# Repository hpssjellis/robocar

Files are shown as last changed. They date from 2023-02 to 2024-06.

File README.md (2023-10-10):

# robocar
Shredder Robot Toy Car Arduino hacked for machine learning with the PortentaH7 and vision shield

Started Feb 12th, 2023

Edgeimpulse Blog about version 1 here  https://docs.edgeimpulse.com/experts/image-projects/arduino-portenta-h7-self-driving-rc-car

Code should end up here in this folder of my Arduino Library the Portenta Pro Community Solutions.  
If you understand the referencing sytem it is in the "dot55" area.

https://github.com/hpssjellis/portenta-pro-community-solutions/tree/main/examples/dot5-portenta-machine-learning/dot55-robocar

## Main Build steps For Version 1.0.0 at [v1-0-0-robot-car/README.md](v1-0-0-robot-car/README.md)

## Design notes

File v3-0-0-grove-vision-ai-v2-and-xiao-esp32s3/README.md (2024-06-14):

Grove with XIAO-ESP32S3 

Grove can be programmed using the IDF Matter programmer
https://wiki.seeedstudio.com/getting_started_with_matter/

or with AT commands
https://wiki.seeedstudio.com/grove_vision_ai_v2_at/

XIAO ESP32S3 needs this board loaded onto the Arduino IDE. If you have multiple boards put a comma no space between them.

```https://raw.githubusercontent.com/espressif/arduino-esp32/gh-pages/package_esp32_index.json```

Demos for both

https://wiki.seeedstudio.com/grove_vision_ai_v2_demo/

essential reading

https://www.hackster.io/mjrobot/computer-vision-at-the-edge-with-grove-vision-ai-module-v2-0003c7

# good site The main sensecraft site. You don't need to put your address

https://sensecraft.seeed.cc/ai/#/device/local

convert your edgeimpulse int8 quantized model from  .lite   to .tflite   (just change drag and drop onto google colab then change the extension from .loite to .tflite)

```
!pip install ethos-u-vela
!!vela --version
```
Now upload your int8 quat file with new extension .tflite and check that it is there in the main upload area
```
!ls
```
Then run this command, replacing filename with your file name

```
!vela filename.tflite --accelerator-config ethos-u55-64

```

The last command should allow uploading the .tflite labelled file and it downloading the proper .tflite file that sensecraft can then install on your grove vision V2 ai

My Colab is at 

https://colab.research.google.com/drive/1y6_UrLV31ou59T00OmHwqDJIT-tcbCMo?usp=sharing

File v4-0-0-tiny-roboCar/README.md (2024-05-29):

Tiny version of the roboCar made with cardboard and a hot glue gun and cheap parts.

See Brian Plancher Trash Car

https://discuss.tinyml.seas.harvard.edu/t/tinyml-trash-car/1201

And this video

https://youtu.be/gmqgAcnKeFU?si=8e7QMSewyc0nc5lP

## May 2024  update

design: 

cardboard and hot glue
various bread board wires  (22 guage)
1 breadboard
1 Ni-MH 6V battery
2 geared motors individually controlled
1 dual motor driver
1 XIAO  basic control testing
or
1 XIAO-esp32s3 with camera for basic machine learing
or
Xiao-esp32   S3 or C6 with Grove Vision AI V2 and RPI camera  for advanced machine learning

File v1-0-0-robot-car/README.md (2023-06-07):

BLOG POST

# Shredder RoboCar with the Arduino PortentaH7 and Vision Shield.

## TINYML, MACHINE LEARNING, EMBEDDED DEVICES, ARDUINO PORTENTA-H7

Jeremy Ellis

May 30, 2023

I wanted a long-term project for students willing to do extra work and interested in both Arduino microcontrollers and Vision Machine Learning. We took an RC car and converted it to be controlled by the Arduino PortentaH7 and then trained a FOMO Vision [EdgeImpulse.com](https://www.edgeimpulse.com/) model to create a self-driving RoboCar. This high-level, long-term project is great for students who want a harder-than-normal challenge.

We picked a certain RC car "[RC Pro Shredder](https://bchobbies.com/products/shredder112scale4wdbrushedmonstertruck)" that did not use a brushless motor as the programming of brushless motors has extra complexity. We also needed a big motor driver, a servo motor (The Shredder steering motor is a DC motor with a potentiometer), connectors, USB cable and USB battery pack, as well as the ability to 3D Print large objects. See [price-list.md](price-list.md)

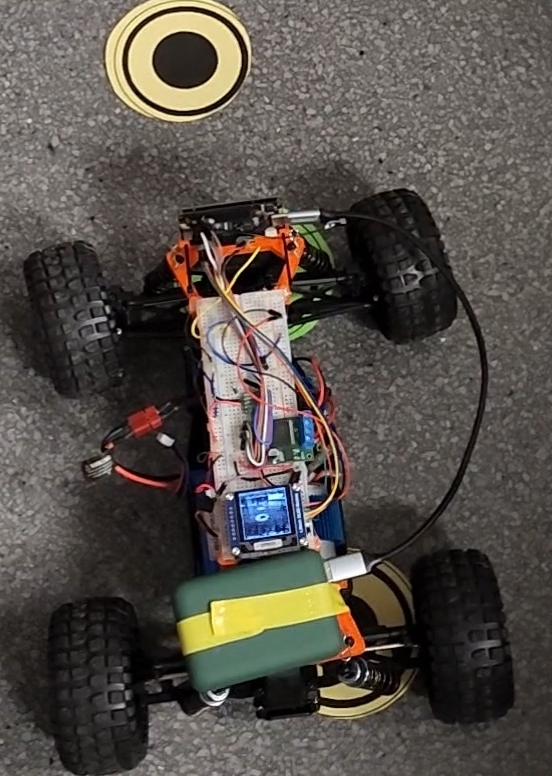
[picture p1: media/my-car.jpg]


## This is a difficult build and may need some adaptations for your project: For example, we used a large print-bed 3D printer to make the 10.5 inch long frame (26.7 cm). You may choose to split that frame up or put the hardware somewhere else on the car.

The software to use is online as part of my Arduino IDE ready library the "[Portenta Pro Community Solutions](https://github.com/hpssjellis/portenta-pro-community-solutions)" in the [dot55 area](https://github.com/hpssjellis/portenta-pro-community-solutions/tree/main/examples/dot5-portenta-machine-learning/dot55-robocar/dot551-robocar-v1). A huge library of ready-made examples to use with the Arduino PortentaH7 and other Arduino MBED boards.

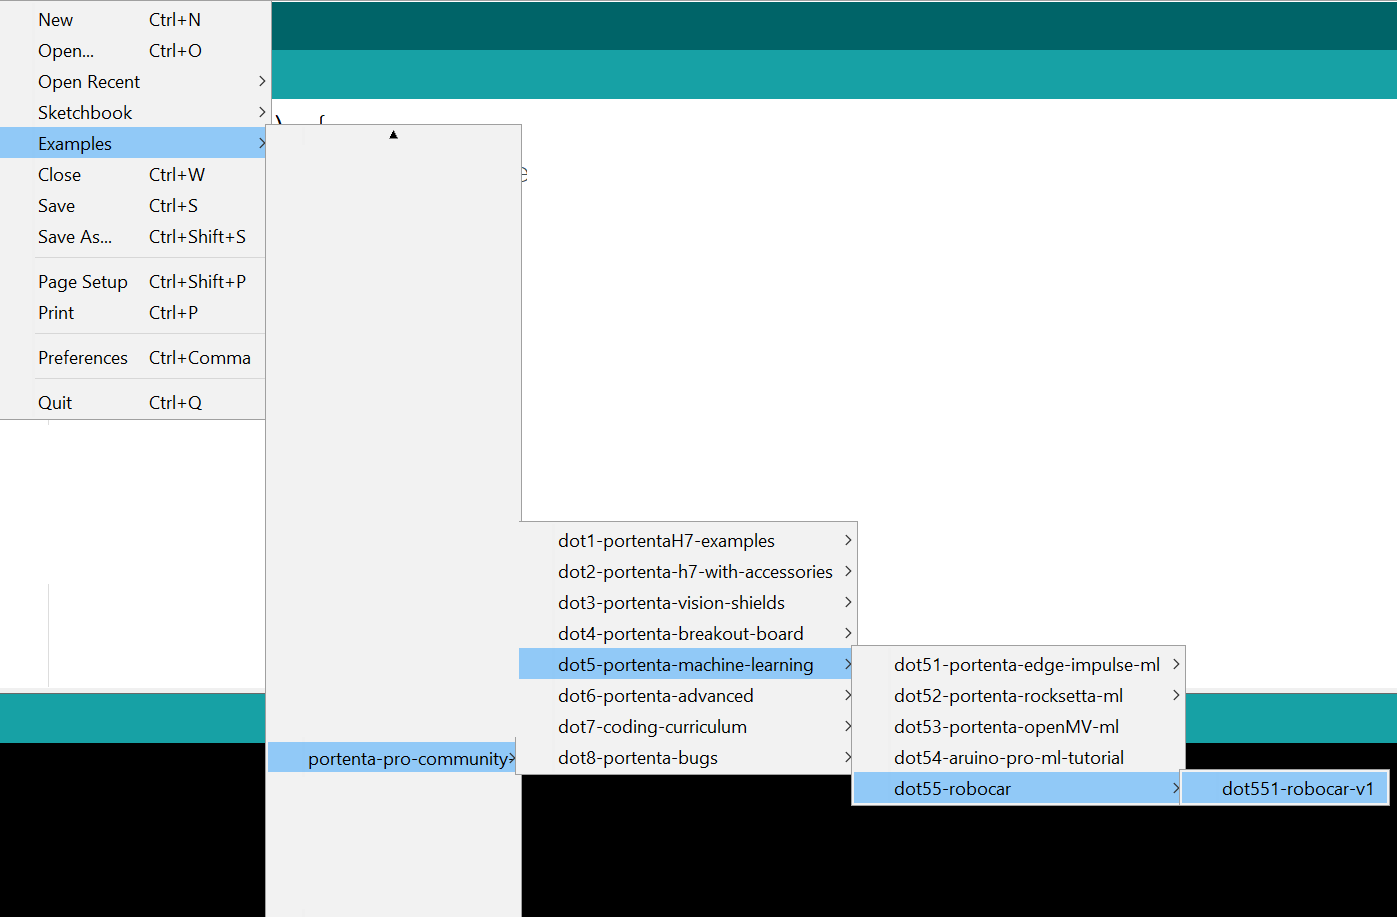
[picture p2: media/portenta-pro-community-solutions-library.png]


## Main Build steps

1. Purchase parts: First, you need to purchase the parts required to build the car. Check out the price list provided and make sure to purchase all the required parts without exceeding your budget. Checkout the price list at [price-list.md](price-list.md)
     ## List of suggested first-time purchases:

      1. [RC-Pro SHREDDER](https://www.rcpro.ca/collections/shredder/products/shredder) $189.99 CDN  
      2. [WSD1302 plug set](https://www.rcsuperstore.com/ws-deans-2-pin-ultra-plug-set-one-male-one-female-included/) 2 sets  $2.99 USD
      2. [Bullet Connectors](https://www.amazon.com/AIRIC-Bullet-Connectors-Insulated-Terminals/dp/B08ZSQZCCR?th=1) only need 2 female bullet connectors this is a set of 50 for  $11.99 USD
      4. [Big VNH5019 Motor Driver Carrier](https://www.pololu.com/product/1451) $44.95 USD 
      5. [3 wire Servo ](https://www.rcpro.ca/collections/shredder/products/shredder-3-wires-19gram-metal-gear-servo)  $24.99 CDN
      6. [Arduino PortentaH7](https://store-usa.arduino.cc/products/portenta-h7)  $103.40 USD 
      7. [Arduino LoRa Vision Shield](https://store-usa.arduino.cc/products/arduino-portenta-vision-shield-lora%C2%AE) $63.25 USD
      8. [https://www.waveshare.com/1.5inch-oled-module.htm](https://www.waveshare.com/1.5inch-oled-module.htm) $12.99 USD
      9. Will also need a USB-C cable, USB battery pack,  micro-sd card and polarized sunglasses. A 3D printer would be useful.

3. Have fun with the RC car: Without breaking it, charge the battery and drive it around to test the tight turning circle diameter and slowest speeds that it still moves.
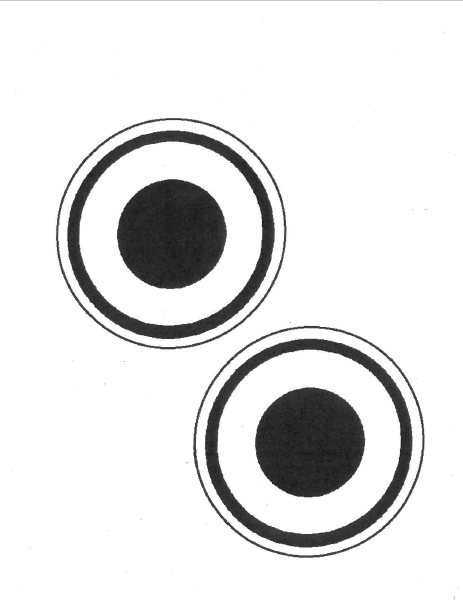
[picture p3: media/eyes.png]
4. Find objects to track: To train your model, you need to find objects to track. You can use double-sided black circles on photocopy paper and cut them out. [../media/eyes-pdf.pdf](../media/eyes-pdf.pdf)   
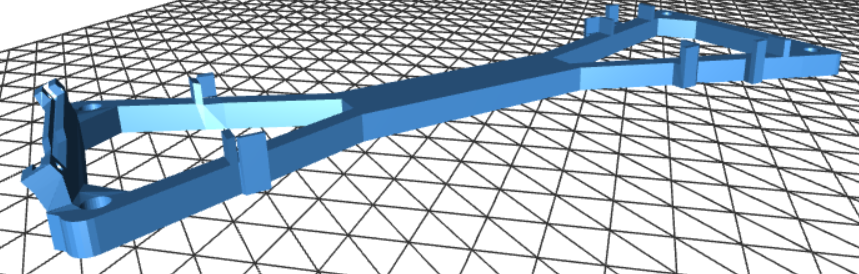
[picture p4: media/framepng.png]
5. Build the car frame:     3D print the car frame using the provided STL files [../media/rc-Car-frame28-22degrees-V28-22-degrees.stl](../media/rc-Car-frame28-22degrees-V28-22-degrees.stl) or these smaller prints [../media/rc-Car-frame27-bread-front.stl](../media/rc-Car-frame27-bread-front.stl)   and [../media/rc-Car-frame27-bread-back.stl](../media/rc-Car-frame27-bread-back.stl) or make one with wood or cardboard. Make sure to attach the PortentaH7 with LoRa vision shield on the car (check the image to see which way the portenta is oriented with the USB cable. The USB cable should protude to the right of the car.) along with a USB-C cable with a battery pack, and attach it to the car while it still has the RC components working. This allows you to drive the car while taking lots of images on the SD card. You will need this program [dot362-png-to-sd-card.ino](https://github.com/hpssjellis/portenta-pro-community-solutions/blob/main/examples/dot3-portenta-vision-shields/dot36-camera-png-to-web/dot362-png-to-sd-card/dot362-p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). Note line 75 ```int myDelay = 10000;``` sets a variable to take an image every 10 seconds. Change that number to about 500 to take lots of .PNG pictures. Depending on how well the Portenta SD Card fits you might get several bad photos. An easy soultion is to just take many more photos. You might want to attach sunglasses to the model if reflections are a problem when using the car inside.

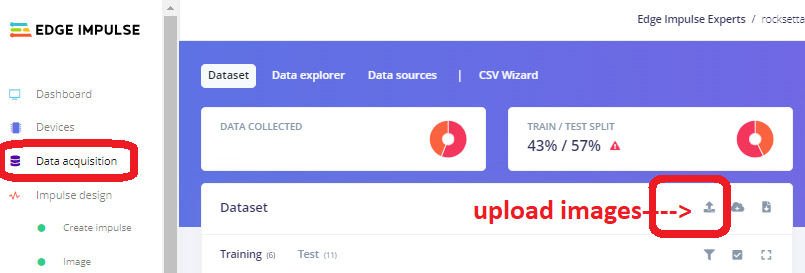
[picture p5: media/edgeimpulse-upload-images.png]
5. Train the model: Upload the images to Edgeimpulse.com  and train a FOMO model on EdgeImpulse.com, or grab the main one I use: [here ei-ei-v25-fomo-eyes-shades-arduino-1.0.2.zip](https://github.com/hpssjellis/portenta-pro-community-solutions/blob/main/zipped-libraries/edge-Impulse/arduino-exported/Portenta-Camera/ei-ei-v25-fomo-eyes-shades-ar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). The following steps to train the machine learning model are mirrored on this site with images at [https://hpssjellis.github.io/multi-language-edgeimpulse-tutorial-vision-cell-phone/](https://hpssjellis.github.io/multi-language-edgeimpulse-tutorial-vision-cell-phone/)
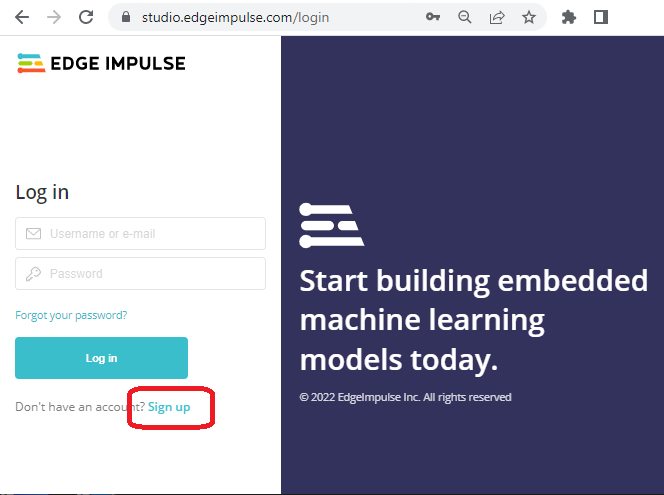
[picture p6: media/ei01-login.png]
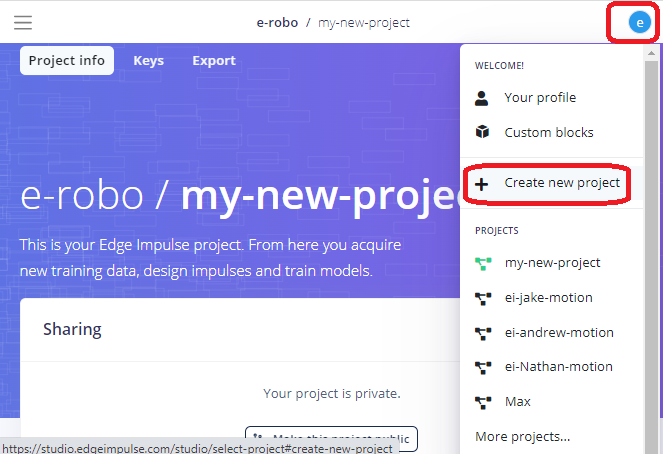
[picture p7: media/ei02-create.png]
      1. login or register for [Edgeimpulse.com](Edgeimpulse.com) <br>  <br> 
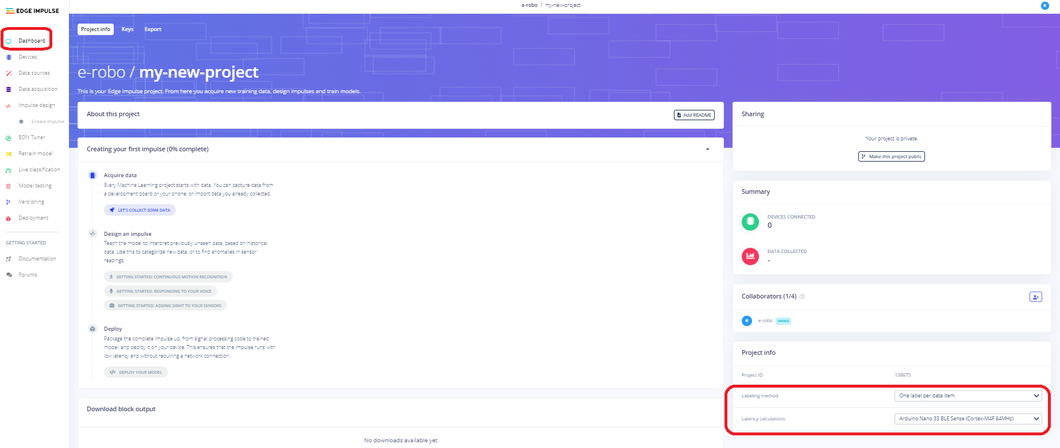
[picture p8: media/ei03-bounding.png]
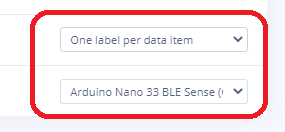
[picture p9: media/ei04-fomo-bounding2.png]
      2. On the dashboard, go to the far right and change the label type from "one label" to "bounding boxes." This sets up the model for FOMO (faster objects, more objects) vision. Also, set Target Device to "Arduino PortentaH7 (Cortex M7 480 MHz)" <br> <br><br>
      3. Use the menu connect devices and go to uploader and upload your images that you took of the car driving around your object to detect
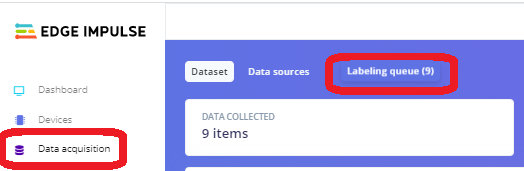
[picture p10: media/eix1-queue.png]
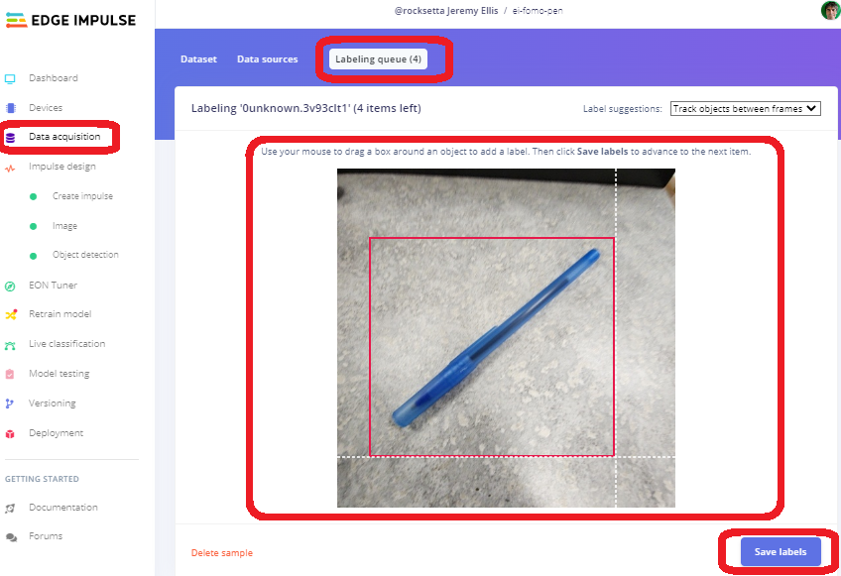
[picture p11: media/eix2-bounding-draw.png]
      4. Go to the menu item Data Acquisition and click on the "Queue" and start drawing bounding boxes around your objects. <br><br> "Make sure the label is the same for all of them I use "1eye". The number in front of your label is very important for an easy way to determine which label you are analyzing . <br>
      5. Once all images are labelled, create your standard FOMO model by clicking "create impulse" and choose the standard Edge Impulse image and object detection blocks. Check before saving the impulse that it has only one object.
      6. For the menu item "image" make sure you are saving Grayscale not RGB and save it. 
      6. In the "Image" menu item, click on "Generate Features" wait a few minutes to see the "Feature explorer". Check for weird images and delete or change them as needed.
      7. In the menu item "Object Detection" set number of training cycles to about 220 (or whatever works for your project). Add "Data Augmentation" and "start Training" takes about 8 minutes.  
      8. Check your F1 score and confusion matrix, which should be reasonably good hopefully above 80% for the background and the 1eye labelled object
      9. Test the model on your phone or download it to the Arduino. A reminder this is an Arduino library so you will need to  upload it into the Arduino IDE as a zipped library.
      10. Check the library file name so you can change the library that is in the default program to the new name.
      11. Always place the car on a small box when testing it as it could jump off the table and break.
      12. Flash the code to the Portenta connected to your car. Make sure both batteries are charged. 
      13. Always unplug both batteries when you have finished testing the car.
      14. Return to Edgeimpulse and try to improve your model.
6. Download the exported Edgeimpulse arduino library and install the .zip file into the Arduino IDE (Sketch--> Include Library --> Add .ZIP Library). This is a long compile depending on your computer speed. Expect about 20 min for this to complete the first time, about 3 min each time after that. Just testing that this code compiles and can load onto the Portenta with vision shield and a serial monitor output shows that it is working is a huge step. Well done if it works.
7. Load the Arduino sketch [dot551-robocar-v1.ino](https://github.com/hpssjellis/portenta-pro-community-solutions/blob/main/examples/dot5-portenta-machine-learning/dot55-robocar/dot551-robocar-v1/dot551-robocar-v1.in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) but loading it is easy from the Arduino IDE installed "Portenta Pro Community Solutions" library sketch dot551 (check for newer versions) as it will also load the included file ```#include "edge-impulse-advanced-v2.h"```. If you want you can manually load that included file from: [edge-impulse-advanced-v2.h](https://github.com/hpssjellis/portenta-pro-community-solutions/blob/main/examples/dot5-portenta-machine-learning/dot55-robocar/dot551-robocar-v1/edge-impulse-advance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). It is just a way to get rid of the complex coding, so your main file only has the necessary code that you might want to change.
8. If you have the (Optional but very useful for debugging) WaveShare grayscale 128 x 128 OLED then attach the correct pins to the Portenta: 
  * black to GND, 
  * red to 3v3, 
  * blue DIN (mosi) to D8, 
  * yellow (sck) to D9, 
  * orange (cs) to D7, 
  * green (dc) to D6, 
  * white (reset) not needed  
<br>and run the code and observe your model if it works. This code [dot229-128x128-gray-oled.ino](https://github.com/hpssjellis/portenta-pro-community-solutions/blob/main/examples/dot2-portenta-h7-with-accessories/dot22-actuators/dot229-128x128-gray-oled/dot229-1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) can be used just to test the WaveShare OLED with the Portenta
9. Remove the 5 wire servo that comes with the shredder car and attach the 3 wire servo. The ball joints are a bit difficult to replace. Test the servo Portenta connection with this code [dot221-servo.ino](https://github.com/hpssjellis/portenta-pro-community-solutions/blob/main/examples/dot2-portenta-h7-with-accessories/dot22-actuators/dot221-servo/dot221-servo.ino)   The connections are:    
   * servo red to 6V battery positive
   * servo ground (brown or black) to 6V battery negative
   * servo ground (brown or black) to board GND
   * servo controller (orange or the other color) to board PWM pin D2   
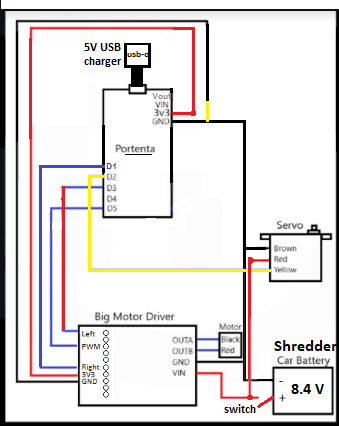
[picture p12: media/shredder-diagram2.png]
Here is an image of the entire wiring diagram  <br>
10. Using a long breadboard attached to the car, connect the Big Motor Drive (Motor Driver test code [dot227-big-dc-motor-driver.ino](https://github.com/hpssjellis/portenta-pro-community-solutions/blob/main/examples/dot2-portenta-h7-with-accessories/dot22-actuators/dot227-big-dc-motor-driver/dot227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) ) See image for pin connections:
  *  Left side of Big Motor Driver board in order from the top (see diagram): D3 - D4 - - D5  3V3  GND - - 
  *  Right side: OutA, OutB to the motor on the Shredder using the [Bullet-Connectors](https://www.amazon.com/AIRIC-Bullet-Connectors-Insulated-Terminals/dp/B08ZSQZCCR?th=1)
  *  Right side continued: GND, VIN to the 7.4 V Li-ion battery on the Shredder using the [ws-deans-2-pin-ultra-plug](https://www.rcsuperstore.com/ws-deans-2-pin-ultra-plug-set-one-male-one-female-included/)  
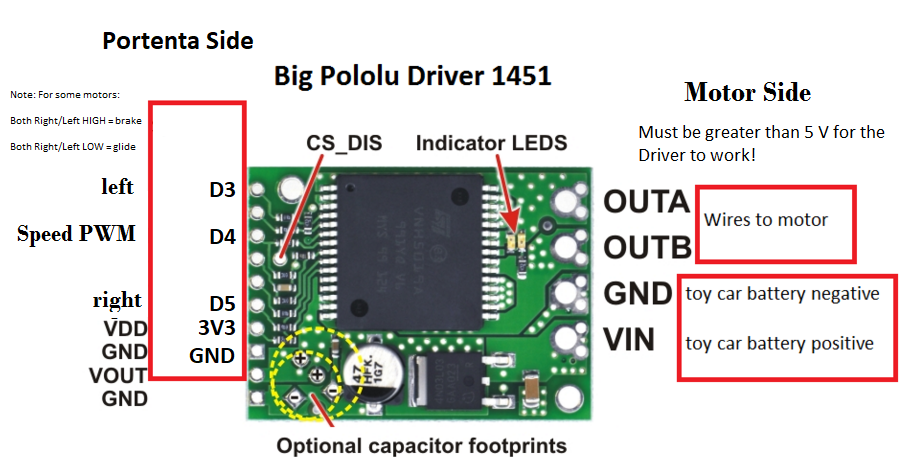
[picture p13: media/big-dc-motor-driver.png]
<br><br> Make sure the high car voltage is kept away from the 5 volt USB input for the Portenta.
11. A tricky part of the car build is getting the main battery power to the big motor driver and deciding on if the main battery is going to power the portenta. We tried step-down 5V regulators etc, but the Portenta seemed very sensitive to power fluctuations when the car was running so I just powered the Portenta with a 5V USB battery pack attached to the top of the breadboard. Your big motor driver will need connectors for both the main battery and the motor. See price list [price-list.md](price-list.md)
12. Test that the mechanical parts of the car are working by running this test code which puts together both the servo and big motor driver: [here ../media/a01-motor-testing.ino](../media/a01-motor-testing.ino). This allows you to check the motor slowest speed and best full turning angle. (Don't push the angles too far as the servo motor complains)
13. Once everything is proven to work, upload the main code again from [here dot551-robocar-v1](https://github.com/hpssjellis/portenta-pro-community-solutions/blob/main/examples/dot5-portenta-machine-learning/dot55-robocar/dot551-robocar-v1/dot551-robocar-v1.in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), (best to load it from hte Portenta Pro Community Solutions library as the included ```edge-impulse-advanced-v2.h``` will be automatically loaded) change a few of the variables such as PWM_MIN and maximum turning angles, and try-out your car.
14. Start editing the code to make it work better.
15. Also edit the 3D Printing to add lights, etc.
16. Share your code on social media and link to twitter @rocksetta 

My student's cars:



# Conclusion

I hope you enjoyed this difficult project, it involved Arduino maker connections to a DC motor and Servo motor with Machine Learning using edgeimpulse.com and problem-solving to improve the Vision FOMO model. When you have the roboCar working, students can start making extensions, such as lighting and battery monitoring, including adaptions for if the car loses the trail. Good luck and I hope you had fun.
<br>

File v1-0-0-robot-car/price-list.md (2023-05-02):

## RoboCar pricelist V1

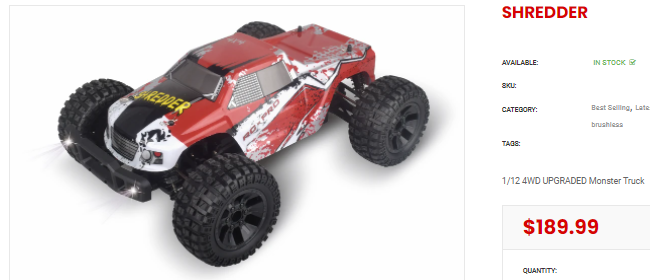
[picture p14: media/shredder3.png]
 [RC-Pro SHREDDER](https://www.rcpro.ca/collections/shredder/products/shredder)   
$189.99 CDN   

(Do not get the more expensive brushless version of the Shredder car as the coding is much more difficult)

# Must also have

 Everyone needs the Big Motor Driver <br>
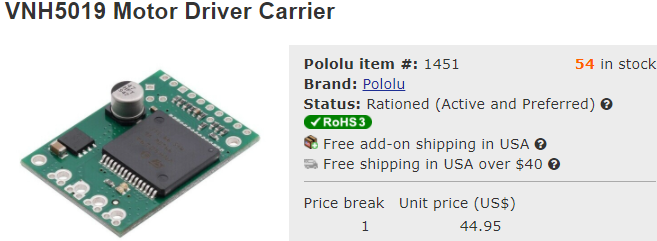
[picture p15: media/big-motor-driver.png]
  [Big VNH5019 Motor Driver Carrier](https://www.pololu.com/product/1451)   
 $44.95 USD

.

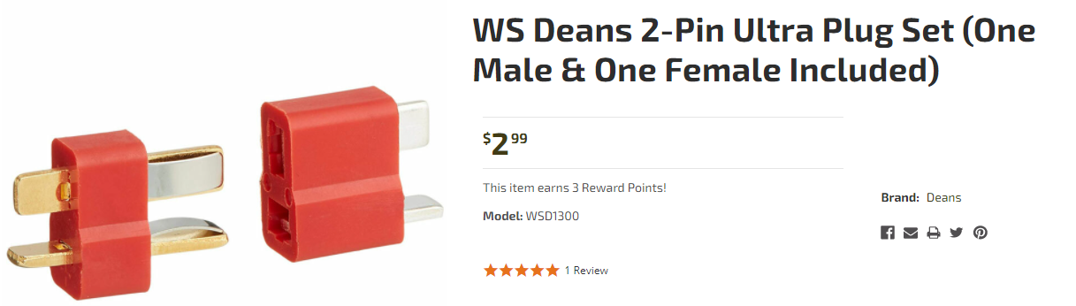
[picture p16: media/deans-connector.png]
 And these plugs you need 2 of the female connector so get 2 sets. https://www.rcsuperstore.com/ws-deans-2-pin-ultra-plug-set-one-male-one-female-included/   

$2.99 USD 

.

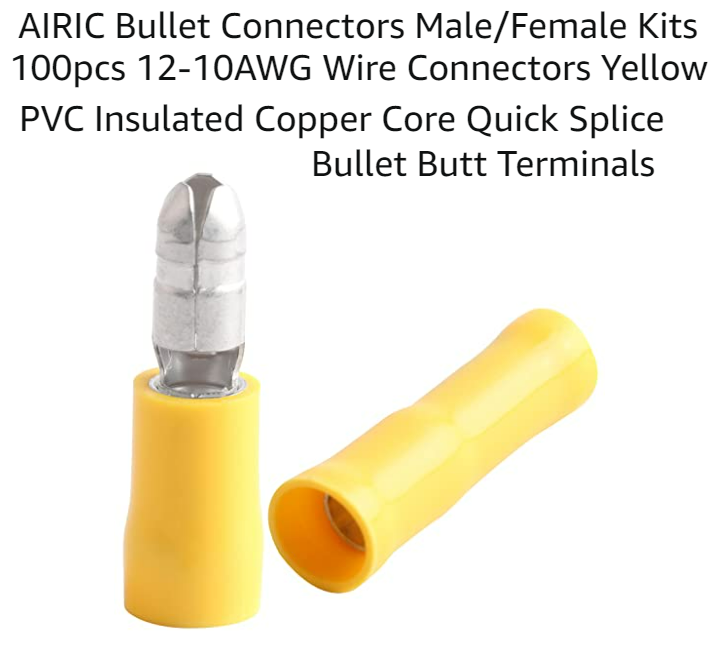
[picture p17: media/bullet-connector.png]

You only need 2 female bullet connectors  https://www.amazon.com/AIRIC-Bullet-Connectors-Insulated-Terminals/dp/B08ZSQZCCR?th=1

this is a set of 50 for  $11.99 USD. 

# Note: 

You can get an extra servo motor as this makes coding much easier than the orginal car above, which uses a DC motor for turning and a potentiometer to determine what angle the motor is at. 
 
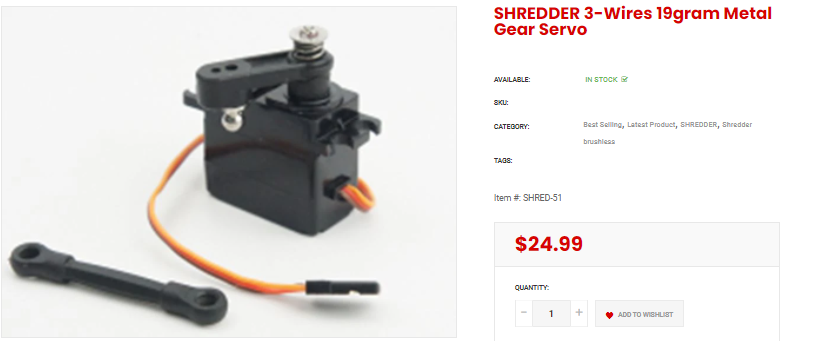
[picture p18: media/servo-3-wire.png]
  Extra [3 wire Servo ](https://www.rcpro.ca/collections/shredder/products/shredder-3-wires-19gram-metal-gear-servo)  

$24.99 CDN

-----

## Note that Microcontrollers improve rapidly. 

Here is the changing list. The 2021 Portenta should last us a few years.   
(Any of the below materials would work fine, just we will be able to do much more with the latest equipment the Portenta and Vision Shield)

## 2021 Microcontroller Price List   
When we combine the PortentaH7 with the LoRa vision shield we have a great Machine Learning duo. But it is expensive.  

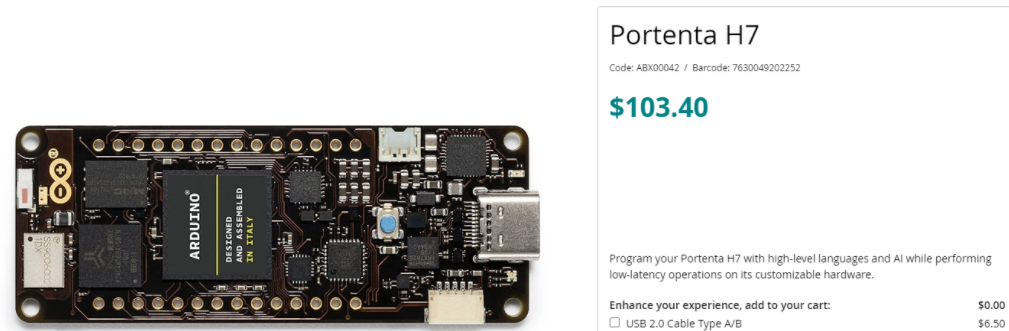
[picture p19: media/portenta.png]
 [Arduino PortentaH7](https://store-usa.arduino.cc/products/portenta-h7)    
$103.40 USD  The base best Arduino

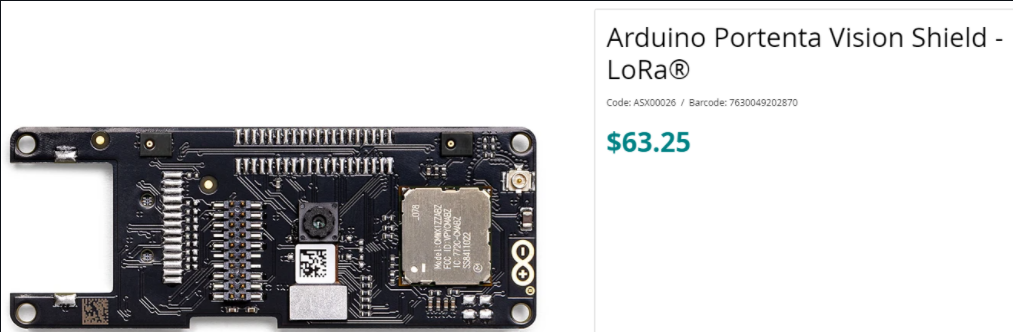
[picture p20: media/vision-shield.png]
 [Arduino LoRa Vision Shield](https://store-usa.arduino.cc/products/arduino-portenta-vision-shield-lora%C2%AE)    
$63.25 USD  allows the Portenta to See and hear and use the LoRaWan networks

The Portenta might need female headers if you don't want to solder wires directly onto it.  Here is a link if you want them. 
The male headers are good to attach the Portenta to a breadboard. Note: The female headers are attached to come up out of the board allowing the HD connectors below the board to connect the Vision shield to.

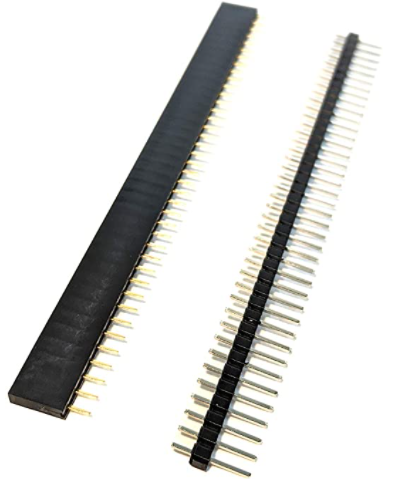
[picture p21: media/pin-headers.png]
 

[10 pack of 40 pin male female headers](https://www.amazon.ca/Pieces-2-54mm-Single-Female-Header/dp/B08CMNRXJ1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)

.

.

## Also to view what you are working on a screen is a good idea

Get the 16 levels of Grayscale Waveshare OLED<br>

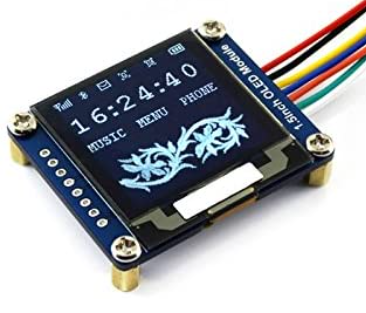
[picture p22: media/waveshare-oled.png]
  [1.5inch OLED Display Module 128x128 16 Gray Scale SPI/I2C Interface SSD1327 Driver Raspberry Pi/Arduino/STM32](https://www.amazon.ca/dp/B079KRC9X3?psc=1&smid=AIVH4OZ6D0Y4K&ref_=chk_typ_imgToDp) $23 CDN 

OR purchase it at [https://www.waveshare.com/1.5inch-oled-module.htm](https://www.waveshare.com/1.5inch-oled-module.htm) 

for $12.99 USD

.

.

...

## List of suggested first time purchase:

1. [RC-Pro SHREDDER](https://www.rcpro.ca/collections/shredder/products/shredder) $189.99 CDN  
2. [WSD1302 plug set](https://www.rcsuperstore.com/ws-deans-2-pin-ultra-plug-set-one-male-one-female-included/) 2 sets  $2.99 USD
2. [Bullet Connectors](https://www.amazon.com/AIRIC-Bullet-Connectors-Insulated-Terminals/dp/B08ZSQZCCR?th=1) only need 2 female bullet connectors this is a set of 50 for  $11.99 USD
4. [Big VNH5019 Motor Driver Carrier](https://www.pololu.com/product/1451) $44.95 USD 
5. [3 wire Servo ](https://www.rcpro.ca/collections/shredder/products/shredder-3-wires-19gram-metal-gear-servo)  $24.99 CDN
6. [Arduino PortentaH7](https://store-usa.arduino.cc/products/portenta-h7)  $103.40 USD 
7. [Arduino LoRa Vision Shield](https://store-usa.arduino.cc/products/arduino-portenta-vision-shield-lora%C2%AE) $63.25 USD
8. [https://www.waveshare.com/1.5inch-oled-module.htm](https://www.waveshare.com/1.5inch-oled-module.htm) $12.99 USD
9. Will also need a usb-C cable, usb battery pack and a micro-sd card polarized sunglasses. A 3D printer might be useful
<br>

Other costs are:  usb-C cable, USB battery pack, 3D Printing ability, general wires and soldering equipment.

## Note: Version 2 is being worked on and will have a slightly different set of hardware

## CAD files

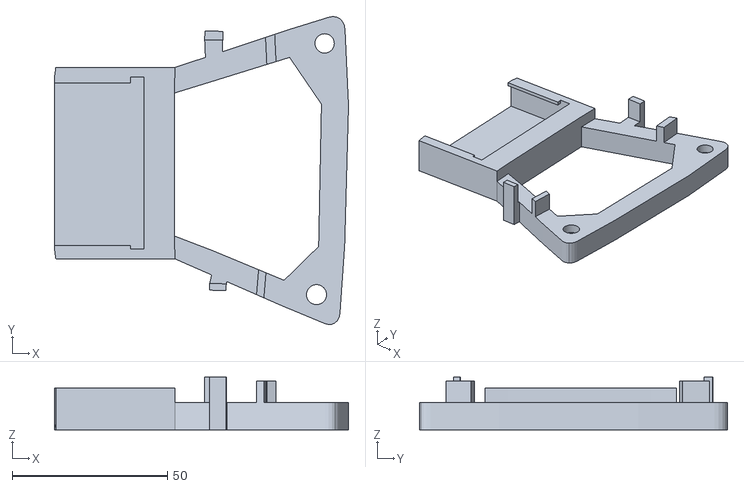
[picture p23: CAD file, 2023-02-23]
media/rc-Car-frame27-bread-back.stl
94.7 x 99.1 x 17.0

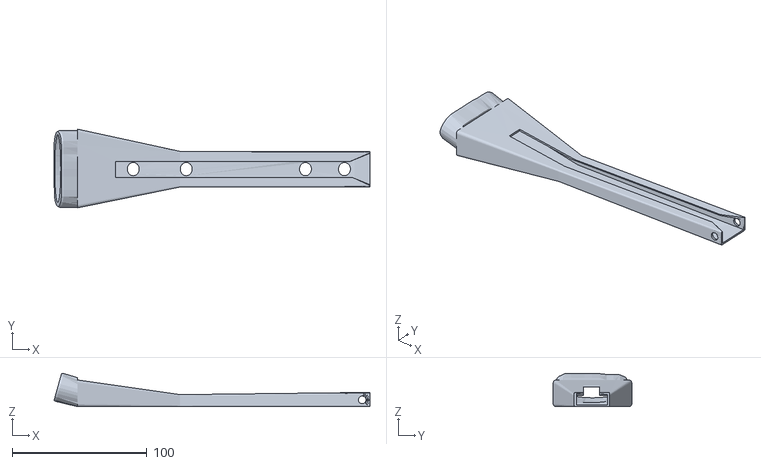
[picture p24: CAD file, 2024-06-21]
v3-0-0-grove-vision-ai-v2-and-xiao-esp32s3/xiao-car06-XIAO-Stick25-base.stl
234.1 x 58.3 x 24.7

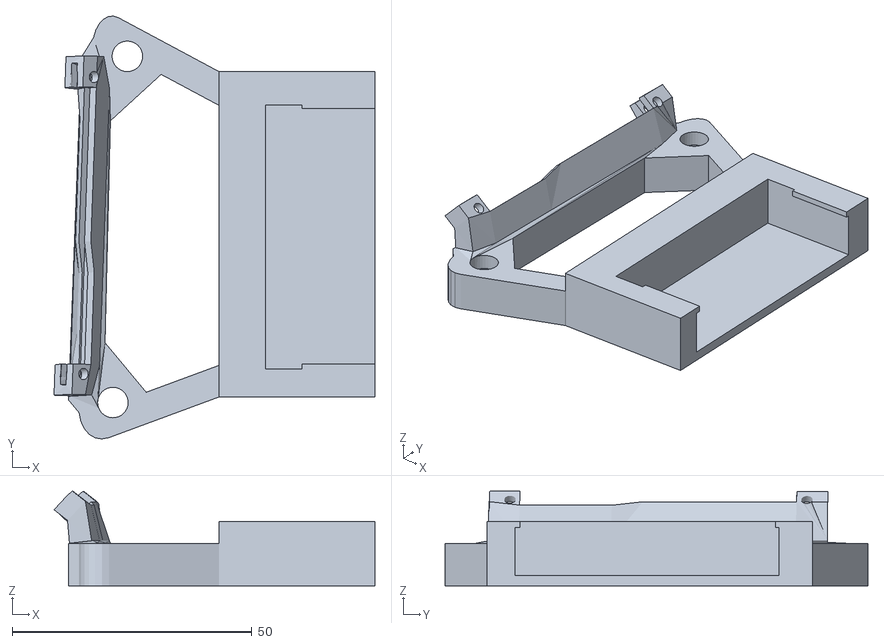
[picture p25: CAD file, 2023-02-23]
media/rc-Car-frame27-bread-front.stl
66.9 x 88.2 x 19.7

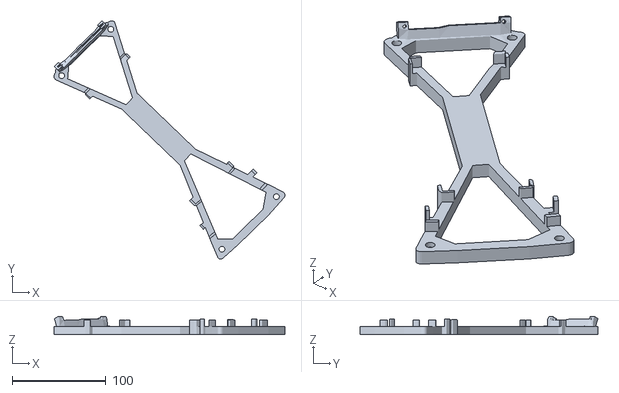
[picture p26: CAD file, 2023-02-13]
media/rc-Car-frame28-22degrees-V28-22-degrees.stl
246.8 x 254.6 x 19.7

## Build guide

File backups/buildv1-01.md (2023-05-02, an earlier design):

# Shredder RoboCar with the Arduino PortentaH7 and Vision Shield.
Needs a big motor driver, servo motor, connectors, usb cable and usb battery pack, ability to 3D Print large objects. See [price-list.md](price-list.md)



## This is a difficult build and may need some adaptations for your project: For example we used a large print-bed 3D printer to make the 10.5 inch long frame (26.7 cm). You may choose to split that frame up or put the hardware somewhere else on the car.

The software to use is online as part of my Arduino IDE ready library the "[Portenta Pro Community Solutions](https://github.com/hpssjellis/portenta-pro-community-solutions)". A huge library of ready made examples to use with the Arduino PortentaH7 and other Arduino MBED boards.



The library is so big I had to make a reference system to find examples. The RoboCar code examples are in the "dot55" area.

https://github.com/hpssjellis/portenta-pro-community-solutions/tree/main/examples/dot5-portenta-machine-learning/dot55-robocar

## Main Build steps

1. Purchase parts: First, you need to purchase the parts required to build the car. Check out the price list provided and make sure to purchase all the required parts without exceeding your budget. Checkout the price list at [price-list.md](price-list.md)
     ## List of suggested first time purchase:

      1. [RC-Pro SHREDDER](https://www.rcpro.ca/collections/shredder/products/shredder) $189.99 CDN  
      2. [WSD1302 plug set](https://www.rcsuperstore.com/ws-deans-2-pin-ultra-plug-set-one-male-one-female-included/) 2 sets  $2.99 USD
      2. [Bullet Connectors](https://www.amazon.com/AIRIC-Bullet-Connectors-Insulated-Terminals/dp/B08ZSQZCCR?th=1) only need 2 female bullet connectors this is a set of 50 for  $11.99 USD
      4. [Big VNH5019 Motor Driver Carrier](https://www.pololu.com/product/1451) $44.95 USD 
      5. [3 wire Servo ](https://www.rcpro.ca/collections/shredder/products/shredder-3-wires-19gram-metal-gear-servo)  $24.99 CDN
      6. [Arduino PortentaH7](https://store-usa.arduino.cc/products/portenta-h7)  $103.40 USD 
      7. [Arduino LoRa Vision Shield](https://store-usa.arduino.cc/products/arduino-portenta-vision-shield-lora%C2%AE) $63.25 USD
      8. [https://www.waveshare.com/1.5inch-oled-module.htm](https://www.waveshare.com/1.5inch-oled-module.htm) $12.99 USD
      9. Will also need a usb-C cable, usb battery pack and a micro-sd card polarized sunglasses. A 3D printer might be useful

3. Have fun with the RC car: Without breaking it, charge the battery and drive it around to test the tight turning circle diameter and slowest speeds that it still moves.
4. Find objects to track: To train your model, you need to find objects to track. You can use double-sided black circles on photo copy paper and cut them out. [../media/eyes-pdf.pdf](../media/eyes-pdf.pdf)
5. Build the car frame: 3D print the car frame using the provided STL files [../media/rc-Car-frame28-22degrees-V28-22-degrees.stl](../media/rc-Car-frame28-22degrees-V28-22-degrees.stl) or these smaller prints [../media/rc-Car-frame27-bread-front.stl](../media/rc-Car-frame27-bread-front.stl)   and [../media/rc-Car-frame27-bread-back.stl](../media/rc-Car-frame27-bread-back.stl) or make one with wood or cardboard. Make sure to attach the PortentaH7 with LoRa vision shield on the car along with a USB-C cable with a battery pack, and attach it to the car while it still has the RC components working. This allows you to drive the car while taking lots of images on the SD card. You will need this program [dot362-png-to-sd-card.ino](https://github.com/hpssjellis/portenta-pro-community-solutions/blob/main/examples/dot3-portenta-vision-shields/dot36-camera-png-to-web/dot362-png-to-sd-card/dot362-p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) You might want to attach sunglasses to the model if reflections are a problem when using the car inside.

5. Train the model: Upload to Edgeimpulse.com and train a FOMO model on EdgeImpulse.com, or grab one provided. [here ei-ei-v25-fomo-eyes-shades-arduino-1.0.2.zip](https://github.com/hpssjellis/portenta-pro-community-solutions/blob/main/zipped-libraries/edge-Impulse/arduino-exported/Portenta-Camera/ei-ei-v25-fomo-eyes-shades-ar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). The following steps to train the machine learning model are mirrored on this site with images at [https://hpssjellis.github.io/multi-language-edgeimpulse-tutorial-vision-cell-phone/](https://hpssjellis.github.io/multi-language-edgeimpulse-tutorial-vision-cell-phone/)
      1. login or register for [Edgeimpulse.com](Edgeimpulse.com)
      2. On the dashboard, go to the far right and change the label type from "one label" to "bounding boxes." This sets up the model for FOMO (faster objects, more objects) vision. Also set Target Device to "Arduino PortentaH7 (Cortex M7 480 MHz)" 
      3. Use the menu connect devices and go to uploader and upload your images that you took of the car driving around your object to detect
      4. Go to menu item Data Aquisiton and click on the "Queue" and start drawing bounding boxes around your objects. "Make sure the label is the same for all of them I use "1eye". The number one in front is very important. 
      5. Once all images are labelled, create your standard FOMO model by clicking "create impulse" and choose the standard Edge Impulse image and object detection blocks. Check before saving the impulse that it has only one object.
      6. For the menu item "image" make sure you are saving Grayscale not RGB and save it. 
      6. In the "Image" menu item, click on "Generate Features" wait a few minutes to see the "Feature explorer". Check for weird images and delete or change them as needed.
      7. In the menuenu item "Object Detection" set number of training cycles to about 220 (or whatever works for your project). Add "Data Augmentation" and "start Training" takes about 8 minutes.  
      8. Check your F1 score and confusion matrix, which should be reasonably good hopefully above 80% for the background and the 1eye labelled object
      9. Test the model on your phone or download it to the Arduino. Reminder this is an Arduino library so you will need to  upload it into the Arduino IDE as a zipped library.
      10. Check the library file name so you can change the library that is in the default program to the new name.
      11. Always place the car on a small box when testing it as it could jump off the table and break.
      12. Flash the code to the Portenta connected to your car. Make sure both batteries are charaged. 
      13. Always unplug both batteries when you have finished testing the car.
      14. Return to Edgeimpulse and try to improve your model.
7. Download the exported Edgeimpulse arduino library and install the .zip file into the Arduino IDE (Sketch--> Include Library --> Add .ZIP Library). This is a long compile depending on your computer speed. Expect about 20 min for this to complete the first time, about 3 min each time after that. Just testing that this code compiles and can load onto the Portenta with vision shiled and a serial monitor output shows that it is working is a huge step. Well done if it works.
8. Load the Arduino sketch [dot551-robocar-v1.ino](https://github.com/hpssjellis/portenta-pro-community-solutions/blob/main/examples/dot5-portenta-machine-learning/dot55-robocar/dot551-robocar-v1/dot551-robocar-v1.in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) but loading it is easy from the Arduino IDE installed "Portenta Pro Community Solutions" library sketch dot551 (check for newer versions) as it will also load the included file ```#include "edge-impulse-advanced-v2.h"```. If you want you can manually load that included file from: [edge-impulse-advanced-v2.h](https://github.com/hpssjellis/portenta-pro-community-solutions/blob/main/examples/dot5-portenta-machine-learning/dot55-robocar/dot551-robocar-v1/edge-impulse-advance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). It is just a way to get rid of the complex coding, so your main file only has the necessary code that you might want to change.
9. If you have the WaveShare grayscale 128 x 128 OLED then attach the correct pins and run the code and observe your model if it works. This code [dot229-128x128-gray-oled.ino](https://github.com/hpssjellis/portenta-pro-community-solutions/blob/main/examples/dot2-portenta-h7-with-accessories/dot22-actuators/dot229-128x128-gray-oled/dot229-1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) can be used just to test the WaveShare OLED with the Portenta
10. Remove the 5 wire servo that comes with the shredder car and attach the 3 wire servo. The ball joints are a bit difficult to replace. Test the servo Portenta connection with this code [dot221-servo.ino](https://github.com/hpssjellis/portenta-pro-community-solutions/blob/main/examples/dot2-portenta-h7-with-accessories/dot22-actuators/dot221-servo/dot221-servo.ino)
11. Using a long breadboard attached to the car, connect the Big Motor Drive (Motor Driver test code [dot227-big-dc-motor-driver.ino](https://github.com/hpssjellis/portenta-pro-community-solutions/blob/main/examples/dot2-portenta-h7-with-accessories/dot22-actuators/dot227-big-dc-motor-driver/dot227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) ) making sure the high car voltage is kept away from the 5 volt USB input Portenta
12. A tricky part of the car build is getting the main battery power to the big motor driver and deciding on if the main battery is going to power the portenta. We tried step-down 5V regulators etc, but the Portenta seemed very sensitive to power fluctuations when the car was running so I just powered the Portenta with a 5V USB battery pack attached to the top of the breadboard. Your big motor driver will need connectors for both the main battery and the motor. See price list [price-list.md](price-list.md)
13. Test that the mechanical parts of the car are working by running this test code which puts together both the servo and big motor driver: [here ../media/a01-motor-testing.ino](../media/a01-motor-testing.ino). This allows you to check the motor slowest speed and best full turning angle. (Don't push the angles too far as the servo motor complains)
14. Once everything is proved to work, upload the main code again, change a few of the variables such as PWM_MIN and maximum turning angles, and try out your car
15. Start editing the code to make it work better
16. Also edit the 3D Printing to add lights, etc.
17. Share your code on social media and link to twitter @rocksetta 

My students cars:



[../media/a01-motor-testing.ino](../media/a01-motor-testing.ino)

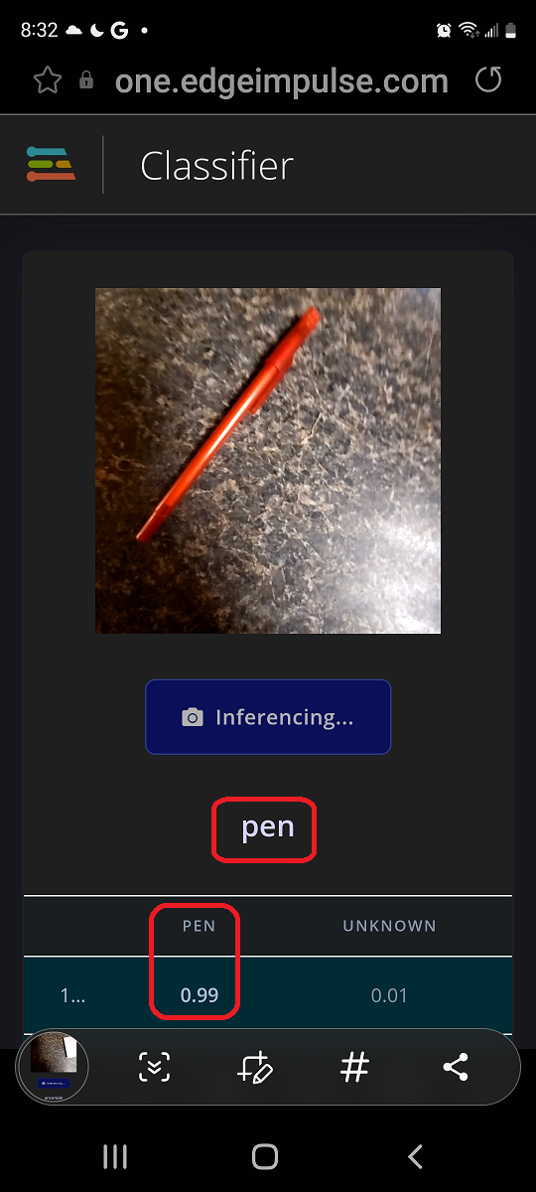
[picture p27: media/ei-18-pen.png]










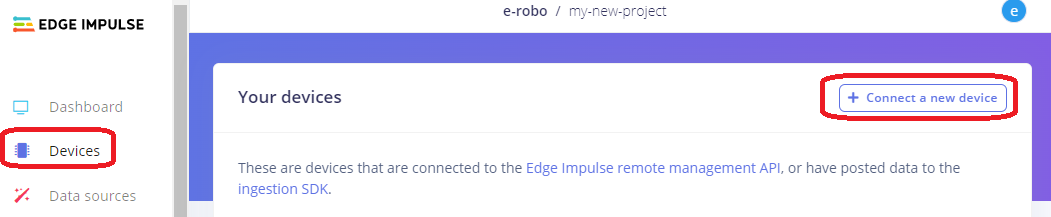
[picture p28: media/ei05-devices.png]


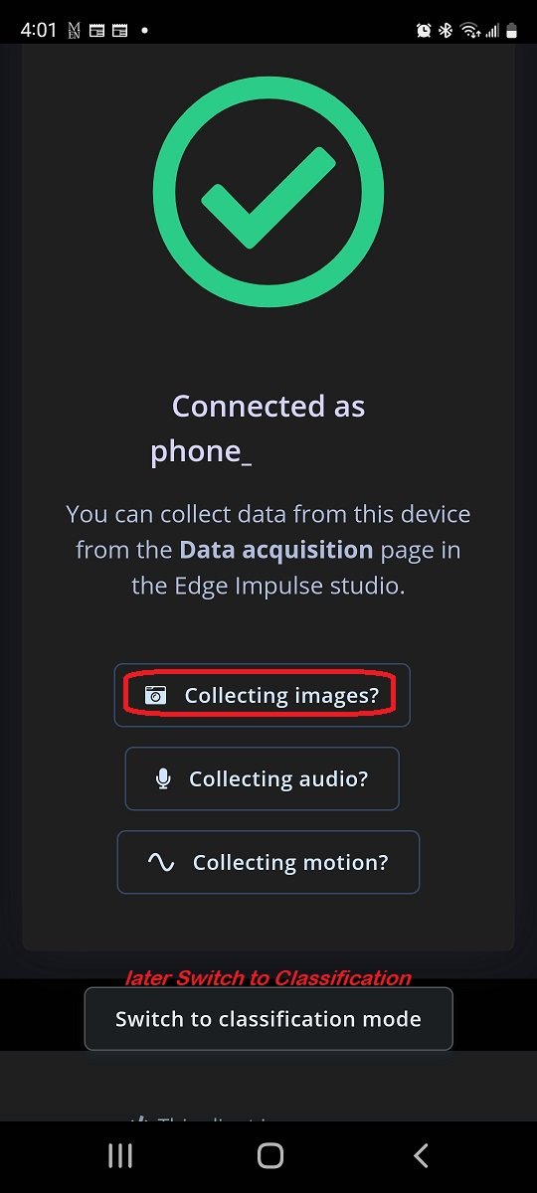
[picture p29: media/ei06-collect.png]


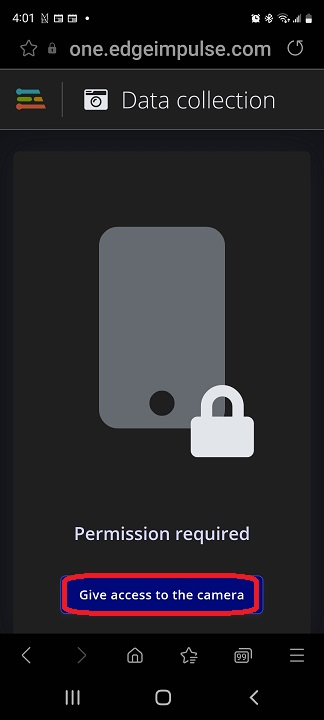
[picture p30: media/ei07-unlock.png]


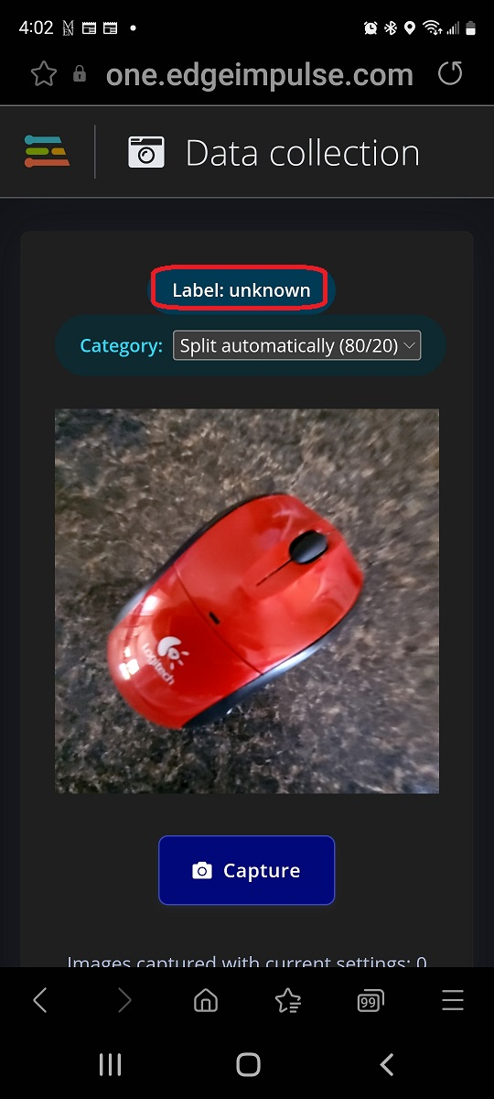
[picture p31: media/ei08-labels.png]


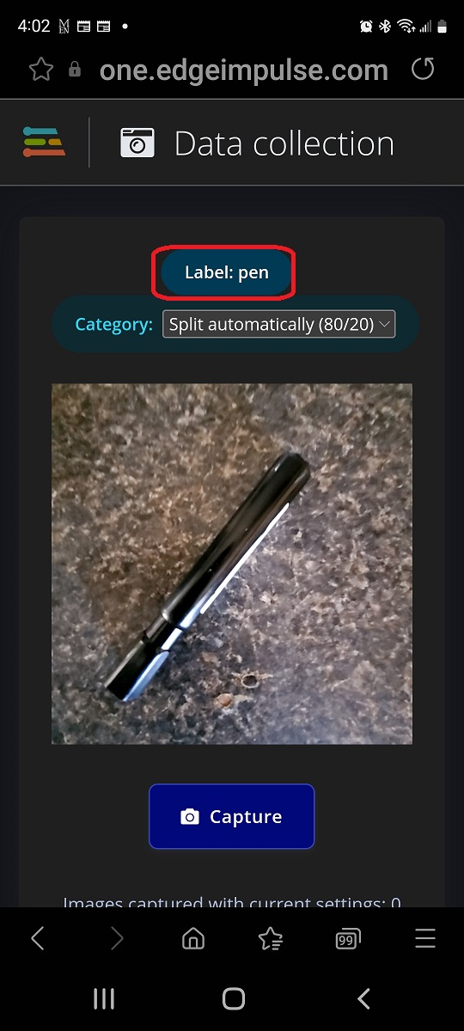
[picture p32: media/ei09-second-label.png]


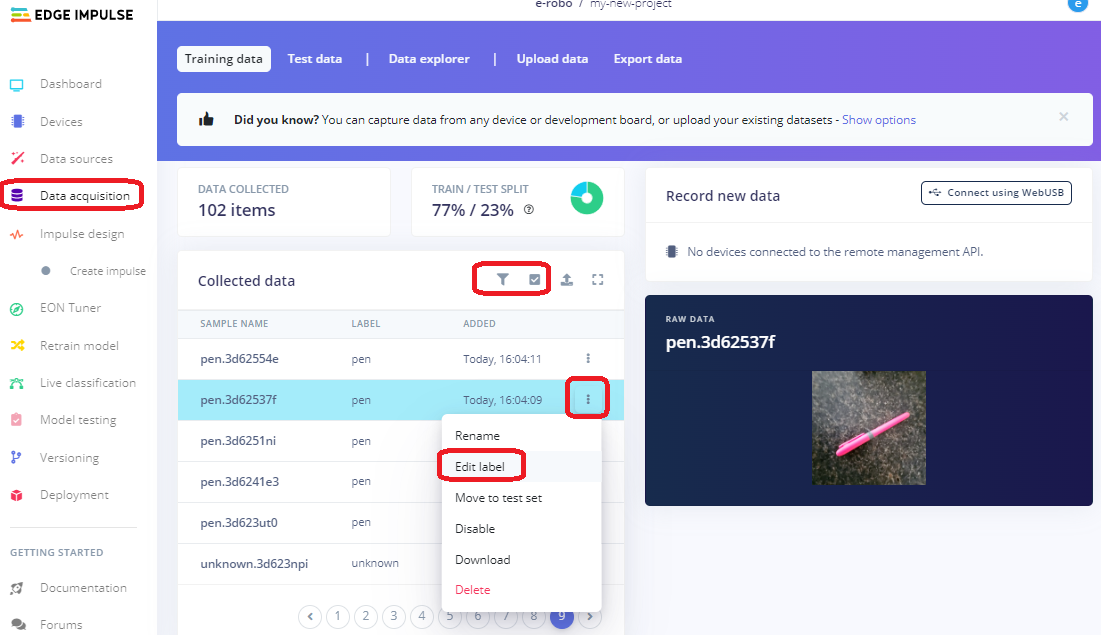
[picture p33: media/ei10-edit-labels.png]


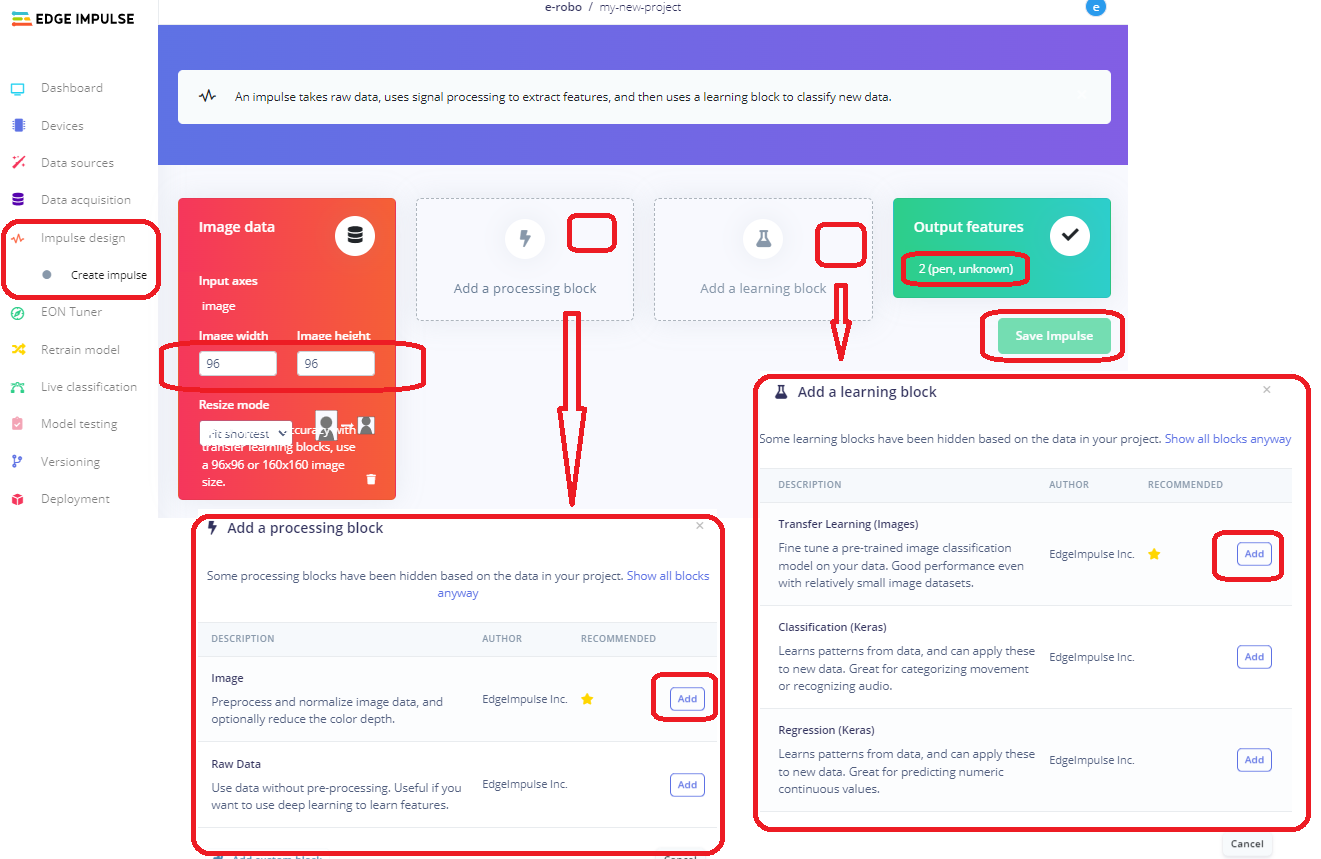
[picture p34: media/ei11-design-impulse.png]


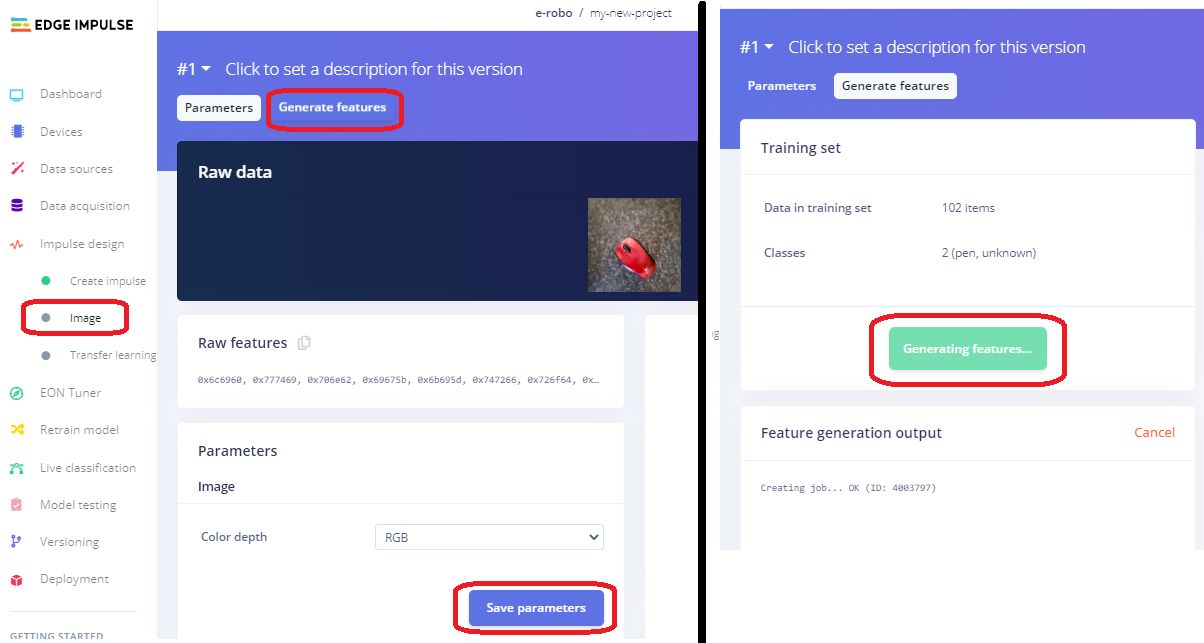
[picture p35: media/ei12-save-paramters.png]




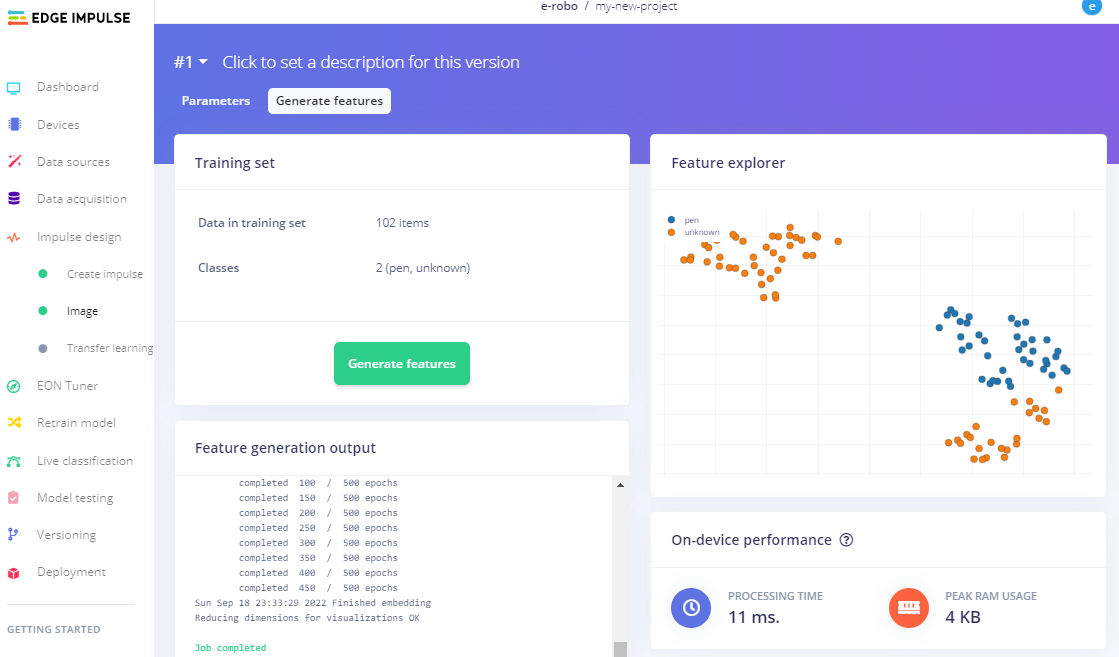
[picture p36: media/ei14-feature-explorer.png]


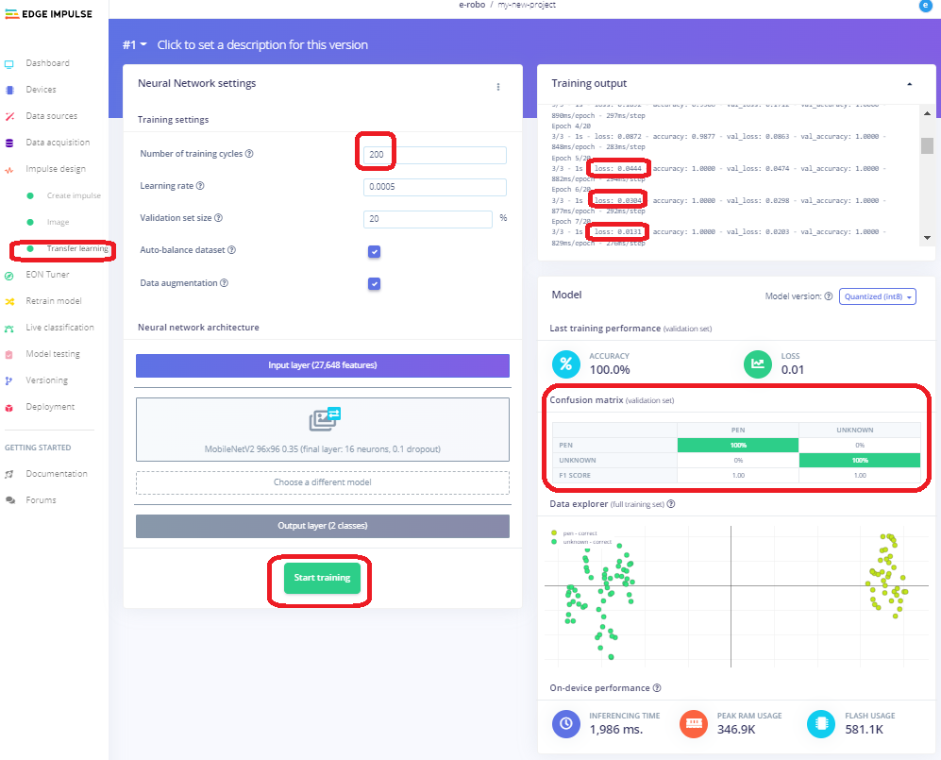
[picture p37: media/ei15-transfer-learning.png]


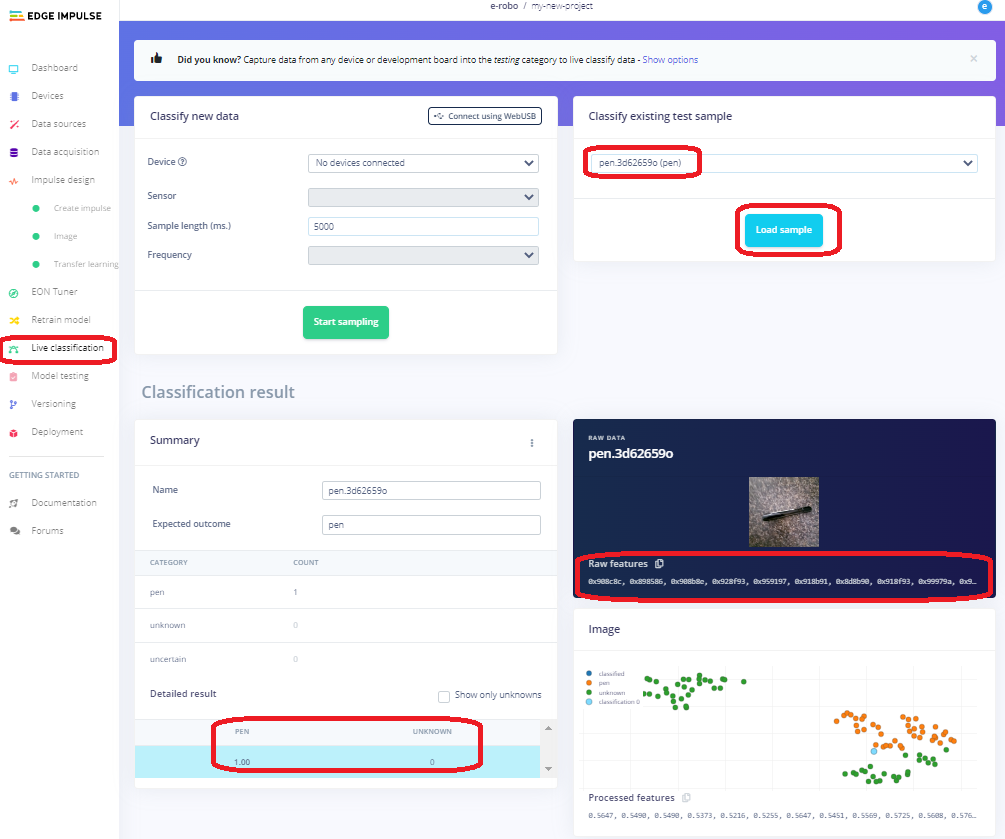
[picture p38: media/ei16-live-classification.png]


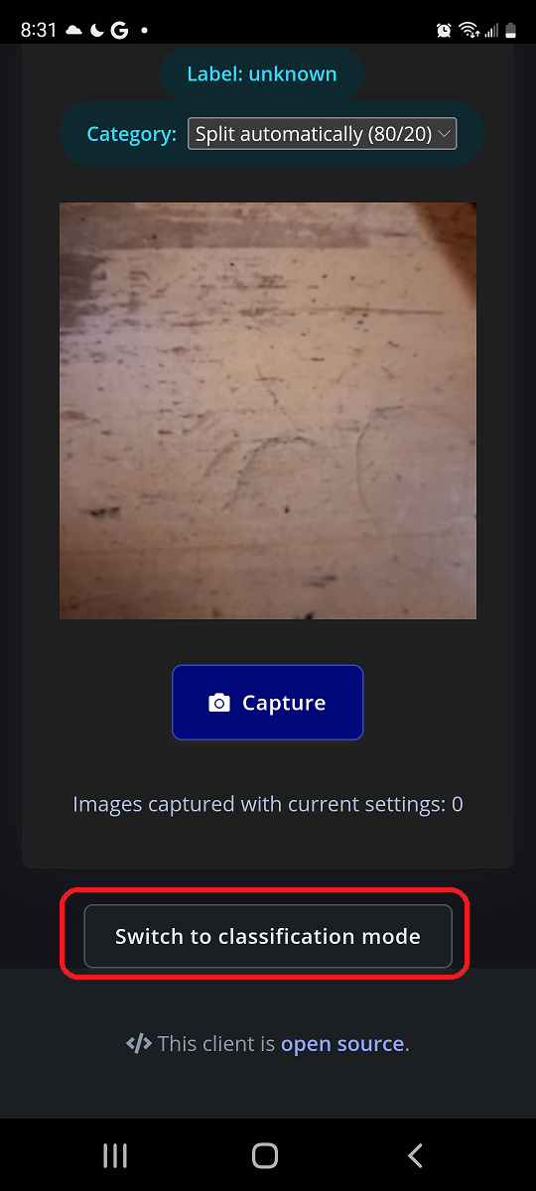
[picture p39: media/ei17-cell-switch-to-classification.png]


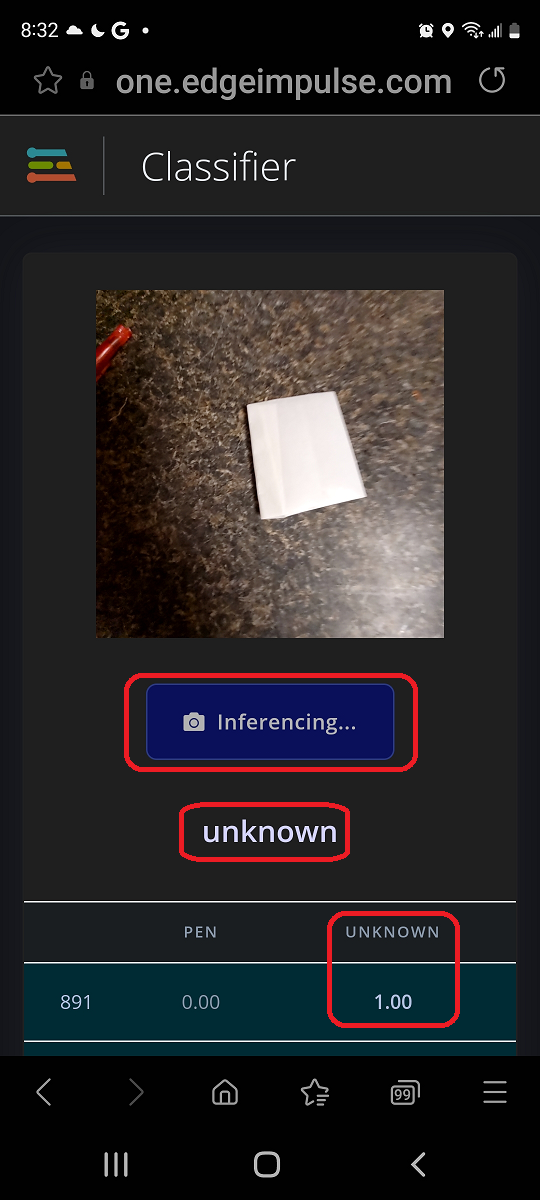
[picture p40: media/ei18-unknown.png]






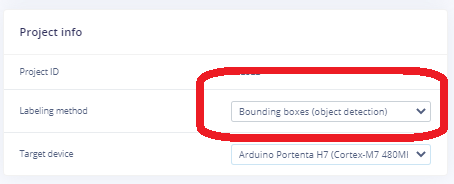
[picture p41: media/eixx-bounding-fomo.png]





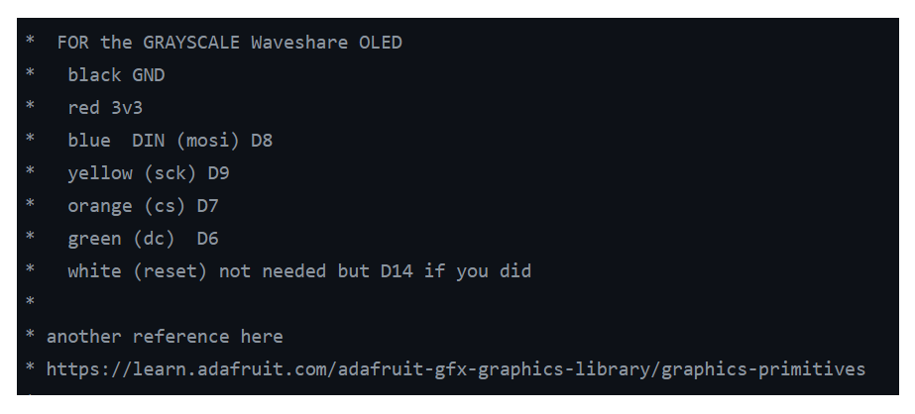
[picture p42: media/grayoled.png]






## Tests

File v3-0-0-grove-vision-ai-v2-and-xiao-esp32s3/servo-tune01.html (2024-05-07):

#include Servo myServo; // Create a servo object void setup() { Serial.begin(115200); // Initialize servo myServo.setPeriodHertz(50); // Servo frequency of 50 Hz int myMinPulse = 500; // Minimum pulse width in microseconds int myMaxPulse = 2500; // Maximum pulse width in microseconds // Attach servo signal to pin 18 with specific min and max pulse widths myServo.attach(18, myMinPulse, myMaxPulse); delay(2000); // Sweep the servo from 0 to 180 degrees for (int pos = 0; pos <= 180; pos++) { myServo.write(pos); delay(15); // Wait 15ms between each position } // Sweep the servo from 180 to 0 degrees for (int pos = 180; pos >= 0; pos--) { myServo.write(pos); delay(15); } } void loop() { int myDelay = 1000; myServo_D2.write(53); delay(myDelay); myServo_D2.write(127); delay(myDelay); myServo_D2.write(90); delay(myDelay); myServo_D2.write(53); delay(myDelay); myServo_D2.write(90); delay(myDelay); myServo_D2.write(127); delay(myDelay); delay(myDelay); }

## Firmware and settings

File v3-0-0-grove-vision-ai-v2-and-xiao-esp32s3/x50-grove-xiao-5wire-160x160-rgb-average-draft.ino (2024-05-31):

/*
 * Connections XIAO-esp32s3 to Grove Vision AI V2 
 * GND to GND
 * 3V3 to 3V3
 * SDA (D4) to SDA grove
 * SCL (D5) to SCL Grove
 * 
 * Connections XIAO-esp32S3 to Servo
 * D2 to Orange wire
 * 
 * Connections XIAO-esp32S3 to Big Motor Driver
 * D0 to top left 1   Digital turn
 * D6 to top left 3   PWM motor speed
 * D1 to top left 6   Digital turn
 * 3V3 to top left 7
 * GND to top left 8
 * 
 * DON'T USE PINS D3 AND D6 ON THE XIAO AS THEY ARE PART OF THE COM WITH THE GROVE.
 */

/*
 * Notes on 5-wire DC turning motor with potentiometer:
 * This servo is actually a DC motor that uses a potentiometer to determine position.
 * The motor has a very small turning radius, approximately 53 degrees to 127 degrees.
 * 
 * Connections:
 * Red - Motor A1
 * Black - Motor A2
 * White - 3V3
 * Yellow - A0
 * Brown - GND
 */

#include <Seeed_Arduino_SSCMA.h>

// Initialize Grove Vision AI
SSCMA AI;

// Define motor and sensor pins
const int myDrivePwmPin  = A0;
const int myTurnPotPin   = A2;
const int myTurnDirPin   = A8;
const int myTurnPwmPin   = A9;

// Define constants and variables for motor control
const int mySlowestSpeed = 53;   
const int myAngleChange  = 10;
const int myMaxAngle     = 4094;   
const int myMinAngle     = 0;      
const int myRealMinX     = 10;     
const int myRealMaxX     = 210;    
const int myNoneMax      = 3;

int myMainSpeed          = 0;  
int myOldSpeed           = 0;   
int myMappedAngle        = 0;
int myOldMappedAngle     = 0;
int myNoneCount          = 0;
int currentPosition      = 0;
int myRandom             = 0;
const int myTurnSpeed    = 255;
const int myTurnOk       = 200;   // 50 allowed error
const int myTurnDelay    = 10;   //15;   // was 9; was OK..... was 5; to short    // time to turn ms

void setup() {
    Serial.begin(115200); 
    pinMode(LED_BUILTIN, OUTPUT);
    
    pinMode(myTurnPwmPin, OUTPUT);
    pinMode(myTurnDirPin, OUTPUT);
    pinMode(myDrivePwmPin, OUTPUT);   


/*

    Serial.println("Ready");   
    delay(5000); 
    Serial.println("Soon");   
    delay(5000); 



       
    Serial.println("motors testing");    
    delay(500);

    // Test motors
    Serial.println("motor testing turn to center");
    //myRandom = random(4000);
    turnMotorToPosition(2045);
    analogWrite(myDrivePwmPin, mySlowestSpeed); // Slowest speed motor test
    delay(500);   
                 
 
    Serial.println("Stop and turn Left");              
    analogWrite(myDrivePwmPin, 0); // Stop motor
   // myRandom = random(4000);
    turnMotorToPosition(100);
    delay(500);     
      
    Serial.println("go and turn right");                
   // myRandom = random(4000);
    turnMotorToPosition(4000);
    delay(500);       
         
    analogWrite(myDrivePwmPin, 0); // Stop motor
    Serial.println("Motor test done");    
    delay(500); 


*/


    Serial.println("Setup Grove AV V2");    
    delay(50);

    AI.begin();  // Initialize Grove Vision AI V2 
    Serial.println("Did it work?");    
    delay(50);
 
}

void loop() {
    if (!AI.invoke()) {
        AI.perf().prepocess;
        AI.perf().inference;
        AI.perf().postprocess;

        Serial.println();
        if (AI.boxes()[0].score > 81 && AI.boxes().size() > 3) {    // 81 gets everything, but too much informaiton
           // myMappedAngle = map(AI.boxes()[0].x, myRealMinX, myRealMaxX, myMaxAngle, myMinAngle);

            float myX, myTotal = 0.0;
            for (int i = 0; i < AI.boxes().size(); i++){
               myX += AI.boxes()[0].x;
            }
            myTotal = myX / AI.boxes().size(); 
            int myTotalInt = (int)myTotal; 
           
           // myMappedAngle = map(AI.boxes()[0].x, myRealMinX, myRealMaxX, myMinAngle, myMaxAngle);
            myMappedAngle = map(myTotalInt, myRealMinX, myRealMaxX, myMinAngle, myMaxAngle);
           // Serial.print(" score:" + String(AI.boxes()[0].score) + ", x:" + String(AI.boxes()[0].x) + ", map:" + String(myMappedAngle) + ", old:" + String(myOldMappedAngle));
            Serial.print(" score[0]:" + String(AI.boxes()[0].score) + ", x[0]:" + String(AI.boxes()[0].x) + " Boxes:" + String(AI.boxes().size()) + ", Total:" + String(myTotalInt) );
            myMainSpeed = mySlowestSpeed;

            turnMotorToPosition(myMappedAngle);

            myNoneCount = 0;
        } else {
            myNoneCount += 1;
            Serial.print(String(AI.boxes()[0].score) + ", None, count:" + String(myNoneCount));
            if (myNoneCount >= myNoneMax) {   
                myMainSpeed = 0;       
                analogWrite(myDrivePwmPin, myMainSpeed);   
                Serial.print(" #"); // stopped since too many none counts
            } 
        }

        if (myOldSpeed != myMainSpeed) {
            analogWrite(myDrivePwmPin, myMainSpeed);   
            Serial.print(" ."); 
            myOldSpeed = myMainSpeed;
        }

        AI.boxes()[0].score = 0;
        AI.boxes().clear();
    }
}

void turnMotorToPosition(int desiredPosition) {
    currentPosition = analogRead(myTurnPotPin);    
    if (desiredPosition < 450 && currentPosition < 1000  ){
       Serial.print(" Danger! Too Low, Desired:" + String(desiredPosition) + ", Current: " + String(currentPosition));
       analogWrite(myTurnPwmPin, 0); //    stop
       return;
    }
     if (desiredPosition > 4000 && currentPosition > 3000 ){
       Serial.print(" Danger! Too High, Desired:" + String(desiredPosition) + ", Current: " + String(currentPosition));
       analogWrite(myTurnPwmPin, 0);  // stop 
       return;
    }
    Serial.print(" Want: " + String(desiredPosition) + ", Now: " + String(currentPosition));

    if (abs(currentPosition - desiredPosition) > myTurnOk) {
        if (currentPosition < desiredPosition) {
            digitalWrite(myTurnDirPin, HIGH); 
            analogWrite(myTurnPwmPin, myTurnSpeed); 
            Serial.print(" >");                     // more right
        } else {
            digitalWrite(myTurnDirPin, LOW); 
            analogWrite(myTurnPwmPin, myTurnSpeed);
            Serial.print(" <");                      // more left
        }
        delay(myTurnDelay); 
        analogWrite(myTurnPwmPin, 0); 
    } else {
        analogWrite(myTurnPwmPin, 0); 
        Serial.print(", |");     // no turn since current and desired position are too close.
    }
    currentPosition = analogRead(myTurnPotPin);  
    Serial.print(", after: " + String(currentPosition));
}

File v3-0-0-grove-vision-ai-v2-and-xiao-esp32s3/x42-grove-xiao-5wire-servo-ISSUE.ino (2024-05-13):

/*
 * Connections XIAO-esp32s3 to Grove Vision AI V2 
 * GND to GND
 * 3V3 to 3V3
 * SDA (D4) to SDA grove
 * SCL (D5) to SCL Grove
 * 
 * 
 * Coonections XIAO-esp32S3 to Servo
 * D2 to Orange wire
 * 
 * Connections XIAO-esp32S3 to Big Motor Driver
 * D0 to top left 1   Digital turn
 * D6 to top left 3    PWM motor speed
 * D1 to top left 6     digital turn
 * 3V3 to top left 7
 * GND to top left 8
 * 
 * 
 * DON'T USE PINS D3 AND D6 ON THE XIAO AS THEY ARE PART OF THE COM WITH THE GROVE.
 * 
 */
/*

// my regular servo is having issues moving as fast aws the grove vision shield can let it so I am going to try the original 5 wire servo
//This servo is actually a DC motor that I will need to use my dual motor driver an a potentiometer that tells where the motor is. 
//This motor has a very small turning radius probably about 53 degrees to 127 degrees like the regular servo


## or the 5 wire dc turning motor with potentiometer on the original shredder and Dual motor driver

// red motor A1      
// black motor A2 
// white 3V3
// yellow A0
// brown GND

Dual Motor Driver
https://github.com/hpssjellis/maker100-eco/blob/main/media/b-b-f-small-dual-dc-motor-driver.png

myTurnPotPin = A2;       // Analog pin for the potentiometer
myTurnDirPin = A4;  // Digital pin for DC motor direction
myTurnPwmPin = A5;     // PWM pin for the motor

Note: the potentiometer goes from 0 to 4095
*/



#include <Seeed_Arduino_SSCMA.h>
//#include <ESP32Servo.h>   // for XIAO-ESP32S3-Sense


SSCMA AI;
//Servo myServo_D2;
int myDrivePwmPin = D0;
int mySlowestSpeed = 53;   // slowest speed that the car moves on a charged battery
int myMainSpeed = 0;  
int myOldSpeed = 0;   

int myMappedAngle = 0;
int myOldMappedAngle = 0;
int myAngleChange = 10;  // was 5 the degrees the servfo will move each time it moves
int myMaxAngle = 4094;   // 133;    // was 127 max right turn on my car
int myMinAngle = 0;      // 53;     // was 53 max left turn on my car
int myRealMinX = 10;     // Should be 0 but is the lowest x reading your vision model gets
int myRealMaxX = 210;    // should be 320 but is the real max reading your vision model gets

int myNoneCount = 0;
int myNoneMax = 3;


// Define the pins for 5 wire turning motor
const int myTurnPotPin = A2;  // Analog pin for the potentiometer
const int myTurnDirPin = A8;  // A4;  // Digital pin for DC motor direction
const int myTurnPwmPin = A9;   // A5; // PWM pin for the motor
int currentPosition    = 0;
int myRandom           = 0;
int myTurnSpeed        = 255;
int myTurnOk           = 50;   // range that we don't have to turn the motor
int myTurnDelay        = 5;    // time to let the motor get somewhere.


void setup(){
    pinMode(myTurnPwmPin, OUTPUT);
    pinMode(myTurnDirPin, OUTPUT);
    pinMode(LED_BUILTIN, OUTPUT);
    Serial.begin(115200); // Updated baud rate
    pinMode(myDrivePwmPin, OUTPUT);   // PWM 0 to 255
   // myServo_D2.attach(D2); // D2 should do PWM on XIOA
    // note the two drive pins on the big motor driver are just connected to GND and 3V3 respectively.

    
    Serial.println("Ready");   
    delay(5000); 
    Serial.println("Soon");   
    delay(5000); 
    
    Serial.println("Setup Grove AV V2");    
    delay(50);
    Serial.println("Did it work?");    
    delay(50);

    AI.begin();  // Grove Vision AI V2 

    Serial.println("motors testing");    
    delay(500);
   // test motors
    Serial.println("motor testing turn to center");
   // myServo_D2.write(90);  
    myRandom = random(4000);
    turnMotorToPosition(myRandom);
    delay(500);
    Serial.println("Go Left");
    analogWrite(myDrivePwmPin, mySlowestSpeed); // slowest speed motor test
   // myServo_D2.write(myMinAngle);
    delay(500);                
    Serial.println("stop turn center");                // wait a bit
    analogWrite(myDrivePwmPin, 0);             // stop motor
    myRandom = random(4000);
    turnMotorToPosition(myRandom);
   // myServo_D2.write(90);
    delay(500);       
    Serial.println("turn right");                // wait a bit
    myRandom = random(4000);
    turnMotorToPosition(myRandom);
   // myServo_D2.write(myMaxAngle);
    delay(500);       
    Serial.println("Motor test done");    
        

}

void loop(){
    if (!AI.invoke() ){

     AI.perf().prepocess;
     AI.perf().inference;
     AI.perf().postprocess;

     Serial.println();
     if (AI.boxes()[0].score > 81 ){
      
      myMappedAngle = map(AI.boxes()[0].x, myRealMinX, myRealMaxX, myMaxAngle, myMinAngle); // x location to angle note reverse numbers 
      Serial.print(" score:"+String(AI.boxes()[0].score) + ", x:" + String(AI.boxes()[0].x) + ", map:" + String(myMappedAngle) + ", old:" + String(myOldMappedAngle) );
      myMainSpeed = mySlowestSpeed;   


      
        
      if (myOldMappedAngle < myMappedAngle - myAngleChange ){
           myOldMappedAngle += myAngleChange;    
           if (myOldMappedAngle > myMaxAngle){myOldMappedAngle = myMaxAngle;}  // protect from maxTurn
           //myServo_D2.write(myOldMappedAngle);                   // turn towards new bigger angle
           turnMotorToPosition(myOldMappedAngle);
          Serial.print(" >");   
          
      } else if (myOldMappedAngle > myMappedAngle + myAngleChange ){
         myOldMappedAngle -= myAngleChange;
         if (myOldMappedAngle < myMinAngle){myOldMappedAngle = myMinAngle;}      // protect from minimum turn
        // myServo_D2.write(myOldMappedAngle - 5);                 // turn towards new smaller angle
         turnMotorToPosition(myOldMappedAngle);
         Serial.print(" <");  
      }  // note: angles  myAngleChange < oldmapped < myAngleChange should not change servo at all





      myNoneCount = 0;  // reset none count since an object found
     } else {
        myNoneCount += 1;
        Serial.print(String( AI.boxes()[0].score)+", None" + ", count:" + String(myNoneCount));
        if (myNoneCount >= myNoneMax) {   // other wise ignore it.
          myMainSpeed = 0;       
          analogWrite(myDrivePwmPin, myMainSpeed);   // No objects detected so stop
          Serial.print(" |"); 
        } 
     }

      if ( myOldSpeed != myMainSpeed){     // test if speed is different
         analogWrite(myDrivePwmPin, myMainSpeed);   
         Serial.print(" ."); 
         myOldSpeed = myMainSpeed;
      }

      AI.boxes()[0].score = 0;  // pre-zero for next loop
      AI.boxes().clear();
    }
  
}
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

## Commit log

2024-04-08 Create x14-grove-xiao-thread
2024-04-23 Create x30-grove-xiao-better-servo-angles
2024-05-02 Create servo-test
